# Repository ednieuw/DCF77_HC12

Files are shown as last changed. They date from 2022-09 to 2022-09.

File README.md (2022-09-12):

# DCF77_HC12
A HC-12 time transmitter with DCF77 time receiver
<h1 class="auto-style3">Arduino Nano Every as DCF77 time-transmitter <br />
with HC-12 433 MHz</h1>
<p class="auto-style1">
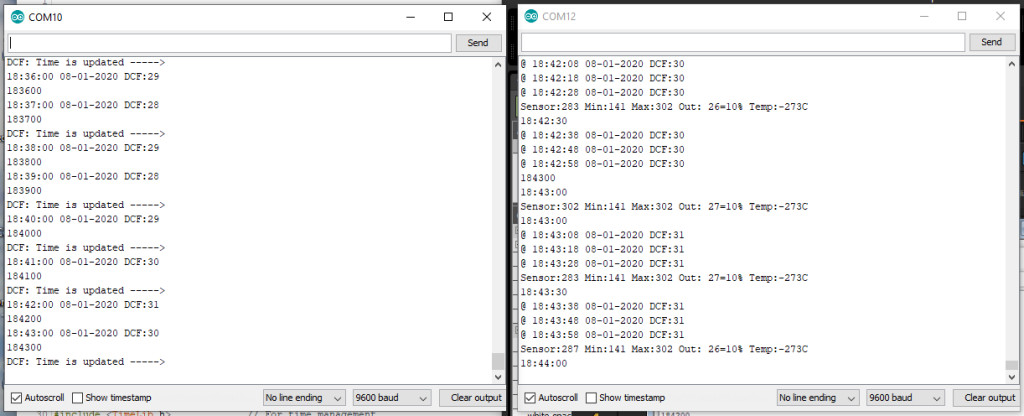
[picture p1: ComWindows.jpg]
Communication windows
<br />
</p>
<p class="auto-style1">The <a href="https://store.arduino.cc/arduino-nano-every">Arduino 
Nano Every</a> board is used to decode a 
DCF77-time signal received with a DCF77-ferrite receiver and transmits time and date 
<br />
with a HC-12 module 
in the air as text.<br />
The DCF77-signal is a pulse that is send every second into the ether with a length of 0.1 or 0.2 second. <br />
The short and long pulse represents a 0 and 1.<br />
When 59 bits are sent the program can extract the time date from this binary 
string. The 60th bit is a second pause without a pulse.<br />
<br />
<strong>Using interrupts</strong><br />
The standard Arduino DCF77-library of Thijs Ellenbaas was used to setup the 
program.<br />
Libraries are a good start but a disadvantage is that from one to the other day they are not available 
anymore. <br />
Because they must be robust and have many functions they often consume more program memory than necessary.<br />
Interrupts are nice but it are interrupts and therefore unpredictable.<br />
</p>
<p class="auto-style1"><strong>A different approach</strong><br />
Arduino programs runs in a loop. In this loop() input is checked and output generated by the subroutines called from within the loop().<br />
In our example the DCF77-signal can be read over 15000 time a second in this loop. <br />
Because the pulses are 0.1 or 0.2 second in length they can be easily discriminated from each other by just counting the 0 and 1 on the digital pin 
attached to the receiver. <br />
<br />
The start time of the counting is irrelevant as long as it is 1000 msec long. It is not necessary to wait for the rising or falling edge of the signal.<br />
Of course there must be enough counts (&gt;1000) in a second. Therefor the program may not use delays is one of its functions.<br />
<br />
The short pulse of 0.1 second must lie between 5% and 15% of the counts and the 1 pulse must lie between 15 and 30%.<br />
As a refinement one can start counting after say 100 successive counts otherwise it is a spike. This value will depend of how many counts a second the program 
can read<br />
This is the variable <em>DCFValidGate</em> in the program. <br />
<br />
In the picture below the DCF-signal with the 60 second-gap is shown.<br />
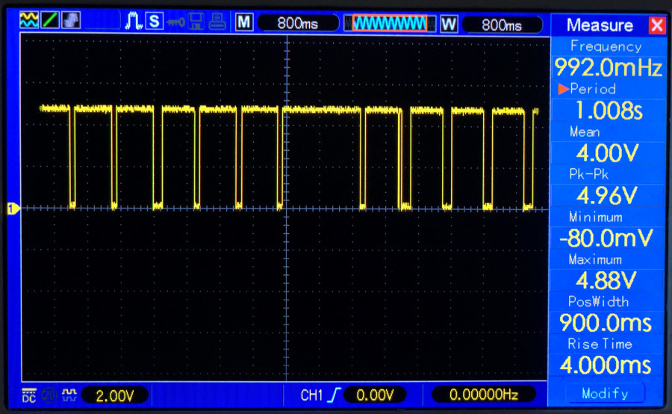
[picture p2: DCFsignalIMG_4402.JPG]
DCF-signal
<br />
<br />
The DCF77-signal is disturbed by microwaves, cheap power supplies and other electronics but also by 
WS2812 and SK6812 colour LED's. <br />
These LED's contain a small chip which frequency disturbs the signal if the 
receiver is close by.<br />
Also receivers that receive DCF49-, DCF39-&nbsp; and HGA22-signals are interfered by these chips.<br />
These RGB-colour chips are used in my <a href="https://ednieuw.nl">word clocks</a>.<br />
In contrast with the other modules like the <a href="https://www.mysensors.org/about/components">NRF24L01</a> 
and several 433 and 866 MHZ Transmitter/Receivers the <a href="https://howtomechatronics.com/tutorials/arduino/arduino-and-hc-12-long-range-wireless-communication-module/">HC-12 module</a> was very easy to implement and worked 
directly without complicated coding. It behaves as an ordinary RS232-connection.<br />
It can also easily be exchanged with HM-05 and HM10 Bluetooth modules without changing the connections and program code.<br />
The <a href="https://github.com/thijse/Arduino-DCF77">DCF-77 library of Thijs Ellenbaas</a> uses an interrupt routine to detect the signal. A tricky thing 
about interrupts is that the trigger is processor dependent and does not work on all pins in the ATMEGA chips. <br />
The usage of the <a href="https://store.arduino.cc/arduino-nano-every">Arduino 
Nano Every</a>&nbsp; was an experiment to see of the time transmitter would work 
with it. <br />
As expected the interrupts were different. For an Arduino Uno and Nano the interrupt number for pin 2 is 0&nbsp;and for the Nano Every 
interrupt number is 2.<br />
<br />
<strong>The hardware</strong><br />
The connections are simple. I used one of the PCB's that are used for the <a href="https://github.com/ednieuw/Fibonacci-Vierkantekokerklok">Fibonacci</a> and 
<a href="https://github.com/ednieuw/Word-Colour-Clock-SK6812-WS2812">Word</a> clocks.<br>
<a href="Colour%20Word%20Clock%20PCBV08-HC-12-DCF77.fzz">The Fritzing file is here</a><br />
The HC-12 module has similar connections as the HC-05 and HM-10 Bluetooth modules.<br />
Only RX and TX are reversed but this is taken care of in the coding.
<pre>
HC_12TX      = 6,    // HC-12 TX Pin
HC_12RX      = 7,    // HC-12 RX Pin </pre>
<p class="auto-style1">
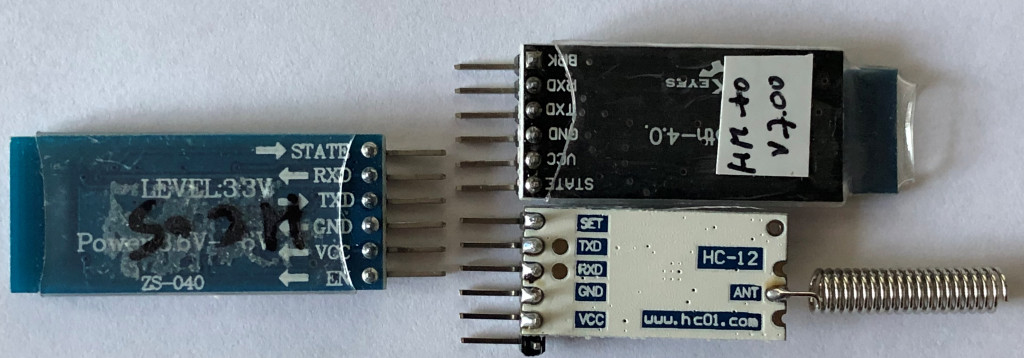
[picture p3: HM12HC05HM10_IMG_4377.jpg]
Connection on modules
<br /><br />
The 1.1K/2.2K voltage divider can be left out. Because several Bluetooth modules are not 5V tolerant a voltage divider is on this PCB to reduce the voltage to 3.3V.
<br />
The HC-12 can be connected directly to the Arduino pins but works also fine with the voltage divider. RX to TX and TX to RX!<br />
On <a href="https://www.allaboutcircuits.com/projects/understanding-and-implementing-the-hc-12-wireless-transceiver-module/">
this page the HC-12</a> and its programming is clearly explained (<a href="Implementing%20the%20HC-12%20Wireless%20transceiver.html">or 
use this link if the site has become obsolete</a>)</p>
<p class="auto-style1"><br />
<table style="width: 950px">
	<tr>
		<td valign="bottom">
		<a href="Colour%20Word%20Clock%20PCBV08-HC-12-DCF77.fzz">
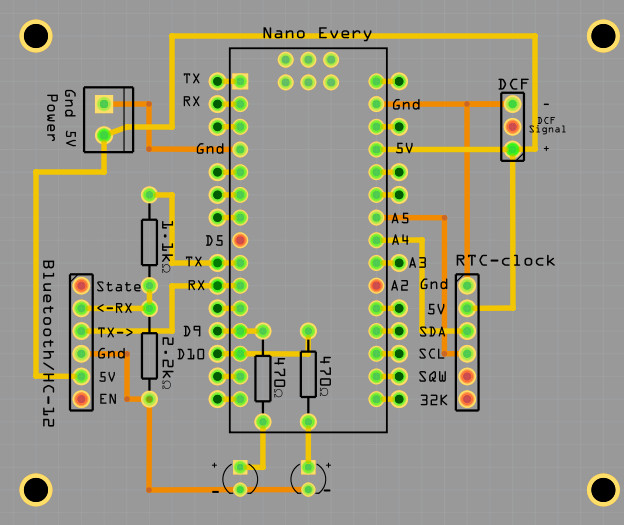
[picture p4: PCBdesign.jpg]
PCB
		</a></td>
		<td valign="bottom">
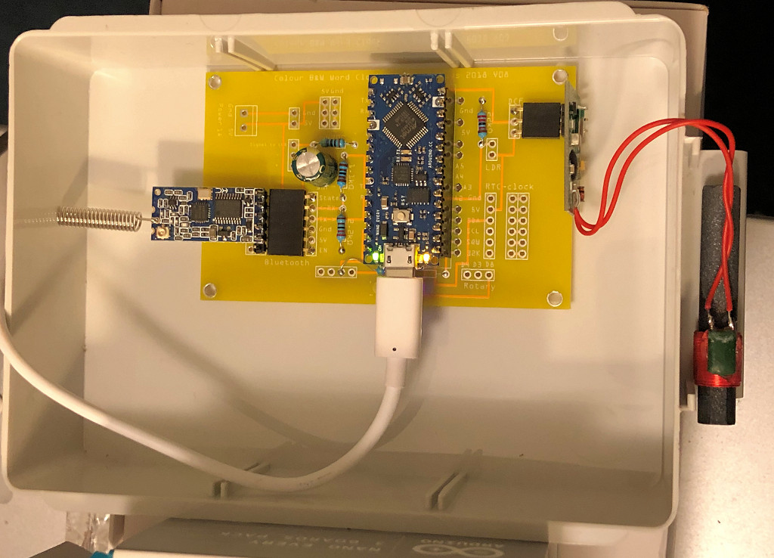
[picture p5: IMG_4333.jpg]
DCFHC12Every
		</td>
	</tr>
	<tr>
		<td valign="bottom">
		<a href="Colour%20Word%20Clock%20PCBV08-HC-12-DCF77.fzz" class="auto-style1">Fritzing PCB</a></td>
		<td valign="bottom">The transceiver running</td>
	</tr>
</table>
<br />
<strong>The program</strong><br />
Can be download here:&nbsp; 
<a href="DCF_HC12TransmitterV06.ino">
DCF_HC12TransmitterV06</a><br />
The libraries needed: <a href="Libraries.zip">Libraries.zip</a><br />
Copy the libraries Adafruit_BusIO, DCF77, NewliquidCrystal, RTClib and Time in the folder named 'libraries' located in your sketch folder<br />
The libraries EEPROM, HID, SoftwareSerial, SPI and Wire are standard default Arduino libraries. Use them only if the compiler can not find them.</p>
<p class="auto-style1">With the #define modules cq coding can be used or disabled. <br />
If no DS3231 module is installed the program uses the Arduino clock. This is fine when the DCF-receiver is working fine<br />
In this case no LCD is installed.</p>
<pre>#define DCFMOD           // Use the Arduino DCF77 library with interrupts
#define DCFTINY          // Use the Tiny DCF algorithm in this program
#define HC12MOD          // Use HC12 time transreceiver Long Range Wireless Communication Module
//#define LCDMOD           // LCD 2 x 16 installed 
#define MOD_DS3231       // DS3231 RTC module installed</pre>
<p class="auto-style1">After declarations, initialisations and the setup 
subroutine the program enters the loop.</p>
<p class="auto-style1"><strong>The loop</strong> is very simple&nbsp;
</p>
<pre>void loop(void)
{
 SerialCheck();
 EverySecondCheck();
 EveryMinuteUpdate();
                              #ifdef DCFMOD         
 DCF77Check();
                              #endif DCFMOD
}</pre>
<span class="auto-style1">The Serial- and DCF77-input is checked every loop and in this program that is over 15000 times a second.
In the EverySecondCheck routine the difference between the last time the routine was entered must be greater than 0.999 seconds.
After 50 msec the seconds tick LED is turned of. With the #ifdef part of the program are compiled or not compiled. <br>
It is wise to leave out program code for parts that are not used. It can only interfere and makes the program larger.
<pre>
</span><strong><span class="auto-style1">Every second</span>
</strong>void EverySecondCheck(void)
{
 if ( millis() - msTick &gt; 50)   { digitalWrite(secondsPin,LOW);}   // Turn OFF the second on pin 13
 if ( millis() - msTick &gt; 999)                                     // Flash the onboard Pin 13 Led so we know something is happening
  {    
   msTick = millis();                                              // second++; 
   digitalWrite(secondsPin,HIGH);                                  // turn ON the second on pin 13
   ++SecPulse;                                                     // second routine in function DimLeds
   GetTijd(0);                                                     // synchronize time with RTC clock      
                           #ifdef LCDMOD
   Print_tijd_LCD();
                           #endif LCDMOD  
                           #ifdef HC12MOD  // disabled with the x HC12MODx
   if( (Inow.second()==10) )               // When HC12 sends it disturbs DCF-signal. In seconds 1 - 19 are whether info bits
    {                                      // Now we can send some info
     sprintf(sptext,"@ %0.2d:%0.2d:%0.2d %0.2d-%0.2d-%0.4d DCF:%0.2d",
            Inow.hour(),Inow.minute(),Inow.second(),Inow.day(),Inow.month(),Inow.year(),DCF_signal);
     HC12.print(sptext);     
    }    
                            #endif HC12MOD
  }
}</pre>
 <class="auto-style1"><strong>Decoding the DCF77-signal</strong>
In the DCF77Check() routine the signal of the DCF77 is updated.
The Arduino library working with interrupts gives a DCFtime==TRUE if a valid time is calculated
In the case of the DCFtiny routine the digital signals are counted and every minute <a href="https://en.wikipedia.org/wiki/DCF77">decoded in UpdateDCFclock()</a>.

A scarcely used "if then else" is used in this routine:
<pre>    if (LastGateValid &gt; DCFValidGate ? SumSecondignal++ : DiscardedSignals++ );
    if (True ? then : else);</pre>
<pre>//--------------------------------------------
void DCF77Check(void)
{
 byte LHbit = 1 - digitalRead(DCF_PIN);        // write inverted DCF pulse to LED on board 
 digitalWrite(DCF_LED_Pin, LHbit ); 
                             #ifdef DCFMOD
 time_t DCFtime = DCF.getTime();               // Check if new DCF77 time is available
 if (DCFtime!=0)
  {
   Tekstprintln("DCF: Time is updated -----&gt;  ");
   sprintf(sptext,"%0.2d%0.2d%0.2d",Inow.hour(),Inow.minute(),Inow.second());
   Tekstprintln(sptext); 
   DCF_signal+=2;
   setTime(DCFtime); 
   RTCklok.adjust(DCFtime);
//   Ellenbaas++;
  }
                             #endif DCFMOD                             
                             #ifdef DCFTINY
 SumSignalCounts += 1;                         // Noof of counted signals  
 if(LHbit) 
   {
    LastGateValid++; 
    if (LastGateValid &gt; DCFValidGate ? SumSecondSignal++ : DiscardedSignals++ );
   }
 if ( millis() - DCFmsTick &gt; 999)              // Compute every second the received DCF-bit to a time 
    { 
      DCFmsTick = millis(); 
      if(byte OKstatus = UpdateDCFclock())     // if after 60 sec a valid time is calculated, sent it to the HC-12 module
         {
          if(OKstatus == 2)                    // if time flag was OK and date flag was NOK
            {
             sprintf(sptext," TIME OK --&gt; %0.2d:%0.2d",Dhour, Dminute );
             Serial.println(sptext);
             RTCklok.adjust(DateTime(Inow.year(), Inow.month(), Inow.day(), Dhour, Dminute, 0));
            }
           else                                // if time flag was OK and date flag also OK  (OKstatus == 1)
            {
            sprintf(sptext," TIME OK --&gt; %0.2d:%0.2d %0.2d-%0.2d-%0.4d/%0.1d",Dhour, Dminute, Dday, Dmonth, 2000+Dyear, Dwday );
            Serial.println(sptext);
            RTCklok.adjust(DateTime(2000+Dyear, Dmonth, Dday, Dhour, Dminute, 0));
            }         
          DCF_signal+=2;
 //         Ed++;
         }
    } 
                             #endif DCFTINY                  
 DCF_signal = constrain(DCF_signal,0 ,100);    // DCF_signal &lt;100
 analogWrite(DCFgood, DCF_signal); 
} 
                             #ifdef DCFTINY
//--------------------------------------------
// CLOCK Make the time from the received DCF-bits
//--------------------------------------------
byte UpdateDCFclock(void)
{
 byte TimeOK;              // return flag is proper time is computed
 if (Bitpos &gt;= 60) {Bitpos=0; StartOfMinute = 0;} 
 if (PrintDebugInfo)
    { 
    sprintf(sptext,"@ %5ld %5ld %3ld %2ld%% Bitpos: %2d",
    SumSecondSignal, SumSignalCounts, DiscardedSignals,  100 * SumSecondSignal/ SumSignalCounts, Bitpos );
    Serial.print(sptext);
    }  
 if (SumSignalCounts&gt;5000 &amp;&amp; SumSecondSignal&lt;500) Bitpos = 59;    // if enough signals the one second no signal is found. this is position zero
 Receivebit = 9;
 int msec = (int)1000 * SumSecondSignal/ SumSignalCounts;   
 switch(msec)
  {
   case   0 ...  50:  Receivebit = 9; break;  // if signal is less than 0.05 sec long than it is nothing
   case  51 ... 150:  Receivebit = 0; break;  // if signal is 0.1 sec long than it is a 0 
   case 151 ... 250:  Receivebit = 1; break;  // if signal is 0.1 sec long than it is a 1 
   default:           Receivebit = 2; break;  // in all other cases it is an error
  }
 if (PrintDebugInfo){ sprintf(sptext," Bit: %1d ",Receivebit );   Serial.print(sptext);}
 switch (Bitpos)                              // Ddecode the 59 bits to a time and date.
  {                                           // It is not binary but "Binary-coded decimal" 
                                              // and blocks are checked with an even parity bit. 
   case   0: if(Receivebit==0)       StartOfMinute = 1;                    break; // Bit must always be 0
   case   1 ... 19: Paritybit = 0;                                         break;
   case  20: if(Receivebit==1)
               {
                StartOfEncodedTime = 1;                      // Bit must always be 1
                Dsecond = Dminute = Dhour = Dday =Dwday = Dmonth = Dyear = 0;
                }
              else StartOfEncodedTime = 0;
                                                                           break;
   case  21: if(Receivebit==1) {Dminute  = 1;  Paritybit = 1 - Paritybit;} break;
   case  22: if(Receivebit==1) {Dminute += 2 ; Paritybit = 1 - Paritybit;} break;
   case  23: if(Receivebit==1) {Dminute += 4 ; Paritybit = 1 - Paritybit;} break;
   case  24: if(Receivebit==1) {Dminute += 8 ; Paritybit = 1 - Paritybit;} break;
   case  25: if(Receivebit==1) {Dminute += 10; Paritybit = 1 - Paritybit;} break;
   case  26: if(Receivebit==1) {Dminute += 20; Paritybit = 1 - Paritybit;} break;
   case  27: if(Receivebit==1) {Dminute += 40; Paritybit = 1 - Paritybit;} break;
   case  28: if(Receivebit==Paritybit) 
               {
                 if (PrintDebugInfo)
                  {                
                   sprintf(sptext,"(Min Parity OK %d %d)" ,Receivebit, Paritybit);
                   Serial.print(sptext);
                  }
                MinOK = 1;
               }
                else 
               {
                 if (PrintDebugInfo)
                  {                
                   sprintf(sptext,"(Min Parity NOK %d %d)",Receivebit, Paritybit);
                   Serial.print(sptext);
                  }
                MinOK = 0;
               }           
             Paritybit = 0;                                               break;  
   case  29: if(Receivebit==1) {Dhour   =  1; Paritybit = 1 - Paritybit;} break;
   case  30: if(Receivebit==1) {Dhour  +=  2; Paritybit = 1 - Paritybit;} break;
   case  31: if(Receivebit==1) {Dhour  +=  4; Paritybit = 1 - Paritybit;} break;
   case  32: if(Receivebit==1) {Dhour  +=  8; Paritybit = 1 - Paritybit;} break;
   case  33: if(Receivebit==1) {Dhour  += 10; Paritybit = 1 - Paritybit;} break;
   case  34: if(Receivebit==1) {Dhour  += 20; Paritybit = 1 - Paritybit;} break;
   case  35: if(Receivebit==Paritybit) 
                {
                 if (PrintDebugInfo)
                   {
                    sprintf(sptext,"(Hour Parity OK %d %d)", Receivebit, Paritybit);
                    Serial.print(sptext);
                   }                        
                  HourOK = 1;
                }
               else 
                {
                  if (PrintDebugInfo)
                   {
                    sprintf(sptext,"(Hour Parity NOK %d %d)",Receivebit, Paritybit); 
                    Serial.print(sptext);
                   }                  
                  HourOK = 0;
                }               
             Paritybit = 0;                                              break;  
   case  36: if(Receivebit==1) {Dday    =  1; Paritybit = 1 - Paritybit;} break;
   case  37: if(Receivebit==1) {Dday   +=  2; Paritybit = 1 - Paritybit;} break;
   case  38: if(Receivebit==1) {Dday   +=  4; Paritybit = 1 - Paritybit;} break;
   case  39: if(Receivebit==1) {Dday   +=  8; Paritybit = 1 - Paritybit;} break;
   case  40: if(Receivebit==1) {Dday   += 10; Paritybit = 1 - Paritybit;} break;
   case  41: if(Receivebit==1) {Dday   += 20; Paritybit = 1 - Paritybit;} break;
   case  42: if(Receivebit==1) {Dwday   =  1; Paritybit = 1 - Paritybit;} break;
   case  43: if(Receivebit==1) {Dwday  +=  2; Paritybit = 1 - Paritybit;} break;
   case  44: if(Receivebit==1) {Dwday  +=  4; Paritybit = 1 - Paritybit;} break;
   case  45: if(Receivebit==1) {Dmonth  =  1; Paritybit = 1 - Paritybit;} break;
   case  46: if(Receivebit==1) {Dmonth +=  2; Paritybit = 1 - Paritybit;} break;
   case  47: if(Receivebit==1) {Dmonth +=  4; Paritybit = 1 - Paritybit;} break;
   case  48: if(Receivebit==1) {Dmonth +=  8; Paritybit = 1 - Paritybit;} break;
   case  49: if(Receivebit==1) {Dmonth += 10; Paritybit = 1 - Paritybit;} break;
   case  50: if(Receivebit==1) {Dyear   =  1; Paritybit = 1 - Paritybit;} break;
   case  51: if(Receivebit==1) {Dyear  +=  2; Paritybit = 1 - Paritybit;} break;
   case  52: if(Receivebit==1) {Dyear  +=  4; Paritybit = 1 - Paritybit;} break;
   case  53: if(Receivebit==1) {Dyear  +=  8; Paritybit = 1 - Paritybit;} break;
   case  54: if(Receivebit==1) {Dyear  += 10; Paritybit = 1 - Paritybit;} break;
   case  55: if(Receivebit==1) {Dyear  += 20; Paritybit = 1 - Paritybit;} break;
   case  56: if(Receivebit==1) {Dyear  += 40; Paritybit = 1 - Paritybit;} break;
   case  57: if(Receivebit==1) {Dyear  += 80; Paritybit = 1 - Paritybit;} break;
   case  58: if(Receivebit==Paritybit) 
               {
                 if (PrintDebugInfo)
                   { 
                    sprintf(sptext,"(Year Parity OK %d %d0", Receivebit, Paritybit );
                    Serial.print(sptext);
                   }
                 YearOK = 1;
               }
             else
               {
                if (PrintDebugInfo)
                  {
                   sprintf(sptext,"(Year Parity NOK %d %d)",Receivebit, Paritybit ); 
                   Serial.print(sptext);
                  }
                 YearOK = 0;
               }
              Paritybit = 0;                                              break;  
    case  59: //Serial.print("silence");
    default:                                                              break;
   }
 Bitpos++;
 if (PrintDebugInfo)
    {
     sprintf(sptext," %0.2d:%0.2d %0.2d-%0.2d-%0.4d/%0.1d %d",Dhour, Dminute, Dday, Dmonth, 2000+Dyear, Dwday, Paritybit);
     Serial.println(sptext);
    }
 SumSecondSignal = SumSignalCounts = DiscardedSignals = LastGateValid = DiscardedSignals = 0;
 if(Bitpos == 59)
   {
   if(StartOfEncodedTime &amp;&amp; MinOK &amp;&amp; HourOK &amp;&amp; YearOK)
     {                                          // check is the time differ only one minute from the previous time
      uint32_t TimeNow = (((((Dyear * 12 + Dmonth) * 31) + Dday) * 24) + Dhour) * 60 + Dminute;
//      sprintf(sptext," Time now  %ld  :: Previous  %ld",TimeNow , TimePrevious); Serial.println(sptext);
      if(TimeNow - TimePrevious &lt;= 2)           // Time is valid if difference with previous time is one minute
        {
         TimeOK = 1;    
        }
      TimePrevious = TimeNow;      
      } 
    else                                        // Time is not valid
      {
       if(StartOfEncodedTime &amp;&amp; MinOK &amp;&amp; HourOK)
         {                                      // check is the time differ only one minute from the previous time
          uint32_t TimeNow = Dhour * 60 + Dminute; 
                                                // sprintf(sptext," HourMinTime now  %ld  :: Previous  %ld",TimeNow , HourMinPrevious); Serial.println(sptext);
          if(abs(TimeNow - HourMinPrevious &lt;= 2))    // Time is valid if difference with previous time is one minute
            {
             TimeOK = 2;    
            }
          HourMinPrevious = TimeNow;         
          }
        else                                    // if no vslid time stamp add one minute to time previous
          {
           TimePrevious++;
           TimeOK = 0;       
          }
       } 
   }                                            // --- end if(Bitpos == 59)
return(TimeOK);
}                 
                             #endif DCFTINY</pre>
<p class="auto-style1"><strong>Rounding up</strong><br />
</p>
<p class="auto-style1">The rest of the program explains it self. <br />
The definition below takes care of the interrupt pin definition of the Nano 
Every and other Arduino's.<br />
</p>
<pre>                    #ifdef ARDUINO_AVR_NANO_EVERY
#define DCF_INTERRUPT 2               // DCF Interrupt number associated with DCF_PIN ( 2 Nano Every)
                    #else if
#define DCF_INTERRUPT 0              // Nano Uno etc 
                    #endif      
DCF77 DCF = DCF77(DCF_PIN,DCF_INTERRUPT,LOW);
                    #endif DCFMOD </pre>
<pre><span class="auto-style1">It is possible to use both DCF decoding routines simultaneously or one of the two. </span>
//#define DCFMOD           // Use the Arduino DCF77 library with interrupts
#define DCFTINY          // Use the Tiny DCF algorithm in this program</pre>
Entering a letter A in the serial monitor switches on and off de debugger for the DCFtiny decoding 
algorithm.<br />
If all the parities are OK and time differs one or two minutes from the previous 
time, date and time are send<br />
If only time parities are OK time is send and not the date.<br />
<br />
The DCFtiny generates earlier and more valid time results than the interrupt 
library.<br />
DCFtiny is probably a little less robust then the interrupt library.<br />
But checking if the received time string from the HC12-transmitter is valid is 
almost obligatory until an CRC-check is 
built in the transmission sentence. <br />
<br />
<br />
<span class="auto-style14"><strong>@ pos cnt tot cnt, DCFValidGate, length%, 
bitpos, bit value, compiled time, compiled date/weekday, parity bit</strong></span><br />
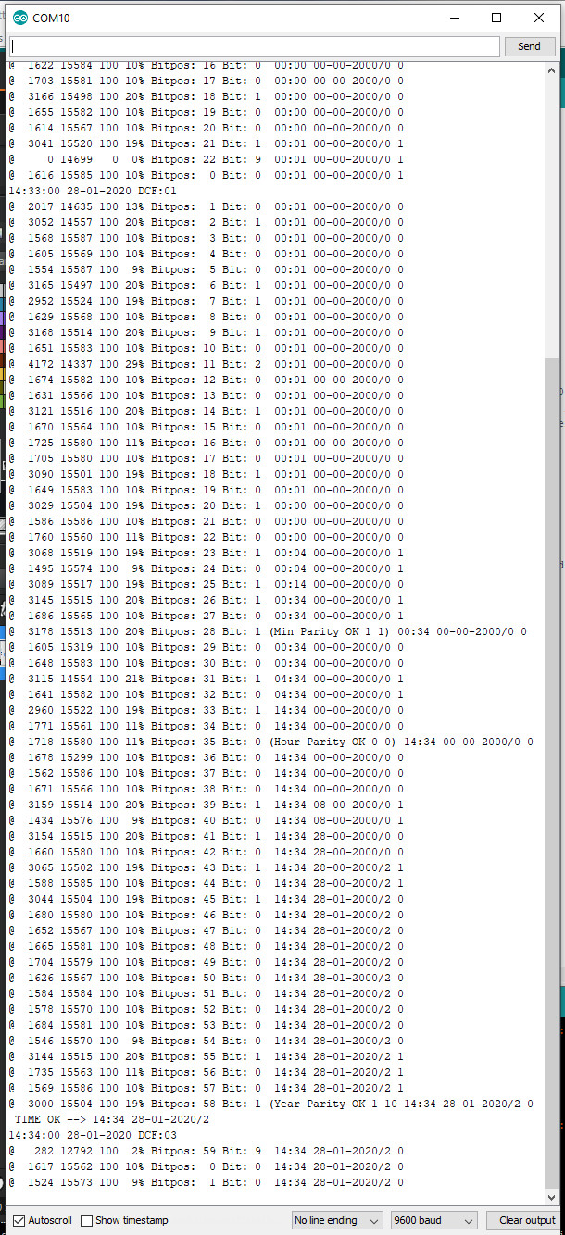
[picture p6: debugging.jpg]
Debugging the signal
<br />
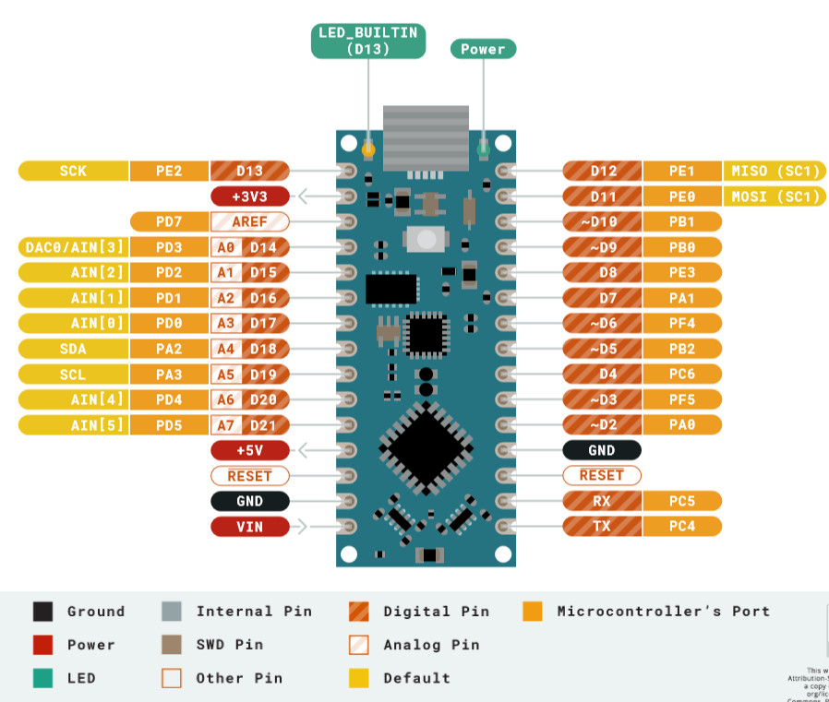
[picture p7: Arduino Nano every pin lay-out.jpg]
Arduino Nano Every pin layout
<br />
<p class="auto-style1">Links</p>
<p class="auto-style1">
<a href="http://www.brettoliver.org.uk/DCF77_Analyzer_Clock/DCF77_Analyzer_Clock.htm">
<span class="auto-style19">Arduino DCF77 Signal Analyzer Clock </span></a>
<span class="auto-style16"><br class="auto-style18" />
</span>
<span class="auto-style16" style="display: inline !important; float: none; background-color: rgb(255, 255, 255); color: rgb(0, 0, 0); font-style: normal; font-variant: normal; font-weight: 400; letter-spacing: normal; orphans: 2; text-align: left; text-decoration: none; text-indent: 0px; text-transform: none; -webkit-text-stroke-width: 0px; white-space: normal; word-spacing: 0px;">
<a href="http://www.hansonline.eu/service/rc.htm"><span class="auto-style18">
Radio Controlled (RC) of Funk klokken</span></a></span><span class="auto-style16"><br class="auto-style18" />
<a href="https://arduino-projekte.webnode.at/meine-projekte/">
<span class="auto-style18">Meine Arduino-Projekte </span></a>
<br class="auto-style18" />
</span>
<a href="http://www.dcf77logs.de/WebConsole.aspx" style="color: rgb(0, 102, 204); font-family: Verdana,Geneva,Tahoma,sans-serif; font-size: 16px; font-style: normal; font-variant: normal; font-weight: 400; letter-spacing: normal; orphans: 2; text-align: left; text-decoration: underline; text-indent: 0px; text-transform: none; -webkit-text-stroke-width: 0px; white-space: normal; word-spacing: 0px;">
<span class="auto-style17">Online signal from Mainflingen on website</span></a><br class="auto-style17" style="color: rgb(0, 0, 0); font-style: normal; font-variant: normal; font-weight: 400; letter-spacing: normal; orphans: 2; text-align: left; text-decoration: none; text-indent: 0px; text-transform: none; -webkit-text-stroke-width: 0px; white-space: normal; word-spacing: 0px;" />
<span class="auto-style17" style="color: rgb(0, 0, 0); font-style: normal; font-variant: normal; font-weight: 400; letter-spacing: normal; orphans: 2; text-align: left; text-decoration: none; text-indent: 0px; text-transform: none; -webkit-text-stroke-width: 0px; white-space: normal; word-spacing: 0px;">
Explains the bits in the received string </span>
<a href="http://arduino-projects4u.com/home-weather-station/" style="color: rgb(0, 102, 204); font-family: Verdana,Geneva,Tahoma,sans-serif; font-size: 16px; font-style: normal; font-variant: normal; font-weight: 400; letter-spacing: normal; orphans: 2; text-align: left; text-decoration: underline; text-indent: 0px; text-transform: none; -webkit-text-stroke-width: 0px; white-space: normal; word-spacing: 0px;">
<span class="auto-style17">Arduino projects 4you</span></a><br class="auto-style17" style="color: rgb(0, 0, 0); font-style: normal; font-variant: normal; font-weight: 400; letter-spacing: normal; orphans: 2; text-align: left; text-decoration: none; text-indent: 0px; text-transform: none; -webkit-text-stroke-width: 0px; white-space: normal; word-spacing: 0px;" />
<span class="auto-style17" style="color: rgb(0, 0, 0); font-family: Verdana,Geneva,Tahoma,sans-serif; font-style: normal; font-variant: normal; font-weight: 400; letter-spacing: normal; orphans: 2; text-align: left; text-decoration: none; text-indent: 0px; text-transform: none; -webkit-text-stroke-width: 0px; white-space: normal; word-spacing: 0px;">
HKW-Elektronik GmbH&nbsp; </span>
<a href="http://www.hkw-shop.de/Empfangstechnik-AM/" style="color: rgb(0, 102, 204); font-family: Verdana,Geneva,Tahoma,sans-serif; font-size: 16px; font-style: normal; font-variant: normal; font-weight: 400; letter-spacing: normal; orphans: 2; text-align: left; text-decoration: underline; text-indent: 0px; text-transform: none; -webkit-text-stroke-width: 0px; white-space: normal; word-spacing: 0px;">
<span class="auto-style17">Sells all kinds of receivers</span></a><br class="auto-style17" style="color: rgb(0, 0, 0); font-style: normal; font-variant: normal; font-weight: 400; letter-spacing: normal; orphans: 2; text-align: left; text-decoration: none; text-indent: 0px; text-transform: none; -webkit-text-stroke-width: 0px; white-space: normal; word-spacing: 0px;" />
<a href="http://www.hjberndt.de/soft/rtctftdcf.html" style="color: rgb(0, 102, 204); font-family: Verdana,Geneva,Tahoma,sans-serif; font-size: 16px; font-style: normal; font-variant: normal; font-weight: 400; letter-spacing: normal; orphans: 2; text-align: left; text-decoration: underline; text-indent: 0px; text-transform: none; -webkit-text-stroke-width: 0px; white-space: normal; word-spacing: 0px;">
<span class="auto-style15"><span class="auto-style18">Rheinturmfunkuhr mit 
Arduino </span></span></a>
<br class="auto-style17" style="color: rgb(0, 0, 0); font-style: normal; font-variant: normal; font-weight: 400; letter-spacing: normal; orphans: 2; text-align: left; text-decoration: none; text-indent: 0px; text-transform: none; -webkit-text-stroke-width: 0px; white-space: normal; word-spacing: 0px;" />
<a href="https://gonium.net/md/2006/11/05/arduino-dcf77-radio-clock-receiver/index.html" style="color: rgb(0, 102, 204); font-family: Verdana,Geneva,Tahoma,sans-serif; font-size: 16px; font-style: normal; font-variant: normal; font-weight: 400; letter-spacing: normal; orphans: 2; text-align: left; text-decoration: underline; text-indent: 0px; text-transform: none; -webkit-text-stroke-width: 0px; white-space: normal; word-spacing: 0px;">
<span class="auto-style17">Arduino DCF77 radio clock receiver ,Matthias 
Dalheimer </span></a>
<br class="auto-style17" style="color: rgb(0, 0, 0); font-style: normal; font-variant: normal; font-weight: 400; letter-spacing: normal; orphans: 2; text-align: left; text-decoration: none; text-indent: 0px; text-transform: none; -webkit-text-stroke-width: 0px; white-space: normal; word-spacing: 0px;" />
<a href="https://github.com/thijse/" style="color: rgb(0, 102, 204); font-family: Verdana,Geneva,Tahoma,sans-serif; font-size: 16px; font-style: normal; font-variant: normal; font-weight: 400; letter-spacing: normal; orphans: 2; text-align: left; text-decoration: underline; text-indent: 0px; text-transform: none; -webkit-text-stroke-width: 0px; white-space: normal; word-spacing: 0px;">
<span class="auto-style15"><span class="auto-style18">Github Thijs Elenbaas</span></span></a><br class="auto-style17" style="color: rgb(0, 0, 0); font-style: normal; font-variant: normal; font-weight: 400; letter-spacing: normal; orphans: 2; text-align: left; text-decoration: none; text-indent: 0px; text-transform: none; -webkit-text-stroke-width: 0px; white-space: normal; word-spacing: 0px;" />
<span class="auto-style17">
<a href="http://www.conrad.com/ce/en/product/641138/DCF-receiver-board" style="color: rgb(0, 102, 204); font-family: Verdana,Geneva,Tahoma,sans-serif; font-size: 16px; font-style: normal; font-variant: normal; font-weight: 400; letter-spacing: normal; orphans: 2; text-align: left; text-decoration: underline; text-indent: 0px; text-transform: none; -webkit-text-stroke-width: 0px; white-space: normal; word-spacing: 0px;">
Conrad receiver</a></span><br />
<a href="https://www.makerguides.com/tm1637-arduino-tutorial/">TM1637 4 Digit 7 
Segment Display Arduino Tutorial </a><br />
<a href="https://www.allaboutcircuits.com/projects/understanding-and-implementing-the-hc-12-wireless-transceiver-module/">
Understanding and Implementing the HC-12 Wireless Transceiver Module</a> </p>
<p class="auto-style1">
&nbsp;</p>
<p class="auto-style1">February 2020</p>
<a href="../../email.html">Ed Nieuwenhuys</a><br /></p>

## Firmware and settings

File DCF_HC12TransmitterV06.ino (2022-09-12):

// =============================================================================================================================
/* 
This Arduino code works on a ATMEGA328 ( Nano Uno), ATMEGA1284 chip and Nano Every
This source contains code for the following modules:  
- RTC DS3231 clock module
- LDR light sensor 5528
- HC-12 Long Range Wireless Communication Module
- DCF77 module DCF-2
The DCF77 module reads the time and date from the German longwave DCF-77 time signal
The time and date are transmitted as ASCII string as hhmmss. (031500 = 15 minutes past 3)
The date is hourly transmitted with a prefic D followed by ddmmyyyy ( D01042020 - 1 april 2020)
Comments are transmitted with a prefix @ (@ 10:07:38 09-01-2020 DCF:16)

Ed Nieuwenhuys 2020
 V06 sep 2022 Removed warnings
 */
// ===============================================================================================================================

//--------------------------------------------
// ARDUINO Definition of installed modules
//--------------------------------------------
#define DCFMOD           // Use the Arduino DCF77 library with interrupts
#define DCFTINY          // Use the Tiny DCF algorithm in this program
#define HC12MOD          // Use HC12 time transreceiver Long Range Wireless Communication Module
#define LCDMOD           // LCD 2 x 16 installed 
#define MOD_DS3231       // DS3231 RTC module installed
//--------------------------------------------
// ARDUINO Includes defines and initialysations
//--------------------------------------------

#include <Wire.h>
#include "RTClib.h"
#include "Time.h"
#include <TimeLib.h>             // For time management 
#include <EEPROM.h>
                     #ifdef LCDMOD
#include <LCD.h>
#include <LiquidCrystal_I2C.h>
                     # endif // LCDMOD
                     #ifdef DCFMOD
#include "DCF77.h"
                     # endif // DCFMOD
                     #ifdef HC12MOD
#include <SoftwareSerial.h>              // For HC12
                     # endif // HC12MOD  
//--------------------------------------------
// PIN Assigments
//--------------------------------------------                      
enum DigitalPinAssignments {      // Digital hardware constants ATMEGA 328 ----
 RX           = 0,                // Connects to TX
 TX           = 1,                // Connects to RX
 DCF_PIN      = 2,                // DCFPulse on interrupt pin
 PIN03        = 3,                // PIN 3
 PIN04        = 4,                // PIN 4
 PIN05        = 5,                // PIN 5
// BT_RX        = 6,                // Tx-pin on BT-mod
// BT_TX        = 7,                // Rx-pin on BT-mod 
 HC_12TX      = 6,                // HC-12 TX Pin
 HC_12RX      = 7,                // HC-12 RX Pin  
 PIN08        = 8,                // PIN 8 
 secondsPin   = 8,                // Seconds
 LED09        = 9,                // PIN 9 
 DCFgood      = 10,               // DCF-signal > 50
 PIN11        = 11,               // PIN 11
 PIN12        = 12,               // PIN 12 
 DCF_LED_Pin  = 13,               // Show DCF-signal
 };
 
enum AnaloguePinAssignments {     // Analogue hardware constants ----
 PhotoCellPin = 2,                // A2
 EmptyA3      = 3,                // A3
 SDA_pin      = 4,                // SDA pin
 SCL_pin      = 5};               // SCL pin

//--------------------------------------------
// HC-12 Long Range Wireless Communication Module
//--------------------------------------------
                     #ifdef HC12MOD
SoftwareSerial HC12(HC_12TX, HC_12RX); //rxPin, txPin, inverse_logic.
                                       //rxPin: the pin on which to receive serial data 
                                       //txPin: the pin on which to transmit serial data
                     # endif // HC12MOD 
//--------------------------------------------
// CLOCK
//--------------------------------------------                                 
#define MAXTEXT 50
static  uint32_t msTick;          // the number of millisecond ticks since we last incremented the second counter
int     count; 
int     Delaytime = 200;
byte    Isecond, Iminute, Ihour, Iday, Imonth, Iyear; 
byte    Dsecond, Dminute, Dhour, Dday, Dmonth, Dyear, Dwday; 
byte    lastminute = 0, lasthour = 0, sayhour = 0;
byte    SecPulse           = 0;   // give a pulse to the Isecond led

const byte MenuItems = 7;          // No of entries in menu
const char menu[MenuItems][MAXTEXT] PROGMEM = {
 "DCF HC12 Transmitter V06",
 "Enter time as:hhmm (1321) or hhmmss (132145)",
 "A DCF Debug info On/Off", 
 "D D15122017 for date 15 December 2017",
 "G for DCF-signalinfo on display",
 "I for this info",
 "Ed Nieuwenhuys" };

//--------------------------------------------
// DS3231 CLOCK MODULE
//--------------------------------------------
#define DS3231_I2C_ADDRESS          0x68
#define DS3231_TEMPERATURE_MSB      0x11
#define DS3231_TEMPERATURE_LSB      0x12

        #ifdef MOD_DS3231
RTC_DS3231 RTCklok;    //RTC_DS1307 RTC; 
        #else
RTC_Millis RTCklok;   
        # endif //
DateTime Inow;
                    #ifdef DCFMOD 
//--------------------------------------------
// DCF-2 DCF77 MODULE
//--------------------------------------------
                    #ifdef ARDUINO_AVR_NANO_EVERY
#define DCF_INTERRUPT 2               // DCF Interrupt number associated with DCF_PIN ( 2 Nano Every)
                    #else
#define DCF_INTERRUPT 0              // Nano Uno etc 
                    # endif //      
DCF77 DCF = DCF77(DCF_PIN,DCF_INTERRUPT,LOW); // HIGH (HKW) or LOW (Reichelt). Some DCF modules invert the signal
                    # endif // DCFMOD 

byte     DCF_signal         = 1;     // is a proper time received? (0 - 100)
                    #ifdef DCFTINY
static   uint32_t DCFmsTick;         // the number of millisecond ticks since we last incremented the second counter
uint32_t SumSecondSignal    = 0;     // sum of digital signal ( 0 or 1)
uint32_t SumSignalCounts    = 0;     // Noof of counted signals
uint32_t DiscardedSignals   = 0;     // Noof of discarded counted signals
uint32_t TimePrevious       = 0;     // Previous minute time and date
uint32_t HourMinPrevious    = 0;     // Previous minute time

byte     Bitpos             = 0;
byte     StartOfMinute      = 0;
byte     StartOfEncodedTime = 0;
byte     Receivebit         = 0;
byte     Paritybit          = 0;
int      LastGateValid      = 0;      // Counter to start recording a DCF-signal after DCFValidGate received
int      DCFValidGate       = 100;    // If LastGateValid reaches this value a DCF-signal is recorded
byte  MinOK, HourOK, YearOK = 0;
                    # endif // DCFTINY
                    #ifdef LCDMOD
//--------------------------------------------
// LCD Module
//--------------------------------------------
LiquidCrystal_I2C lcd(0x27,2,1,0,4,5,6,7); // 0x27 is the I2C bus address for an unmodified backpack
                    # endif // 
//----------------------------------------
// Common
//----------------------------------------
byte PrintDebugInfo         = 0;      // for showing debug info for DCFTINY
char sptext[MAXTEXT+2];               // for common print use    
int  MilliSecondValue       = 999;    // The duration of a second  minus 1 ms. Used in Demo mode
uint32_t Ed =0, Ellenbaas = 0;
// --------------------------------------------------------------------------
// End Definitions                                                    
// --------------------------------------------------------------------------
//--------------------------------------------
// ARDUINO Loop
//--------------------------------------------
void loop(void)
{
 SerialCheck(); 
 EverySecondCheck();
 EveryMinuteUpdate();
//                              #ifdef DCFMOD         
 DCF77Check();
//                              # endif // DCFMOD
}  
//--------------------------------------------
// ARDUINO Setup
//--------------------------------------------
void setup()
{                                        
 Serial.begin(9600);                                                // Setup the serial port to 9600 baud                                                        // Start the RTC-module  
 Wire.begin();                                                      // Start communication with I2C / TWI devices                            
 pinMode(DCF_LED_Pin, OUTPUT);                                      // For showing DCF-pulse or other purposes
 pinMode(DCF_PIN,     INPUT_PULLUP);
// pinMode(BT_State,    INPUT_PULLUP);
// pinMode(BT_Break,    OUTPUT );   
 pinMode(DCFgood,     OUTPUT );  
 pinMode(secondsPin,  OUTPUT );
                              #ifdef MOD_DS3231
 RTCklok.begin();                                                   // start the RTC-module
                              # else
 RTCklok.begin(DateTime(F(__DATE__), F(__TIME__)));                 // if no RTC module is installed use the ATMEGAchip clock
                              # endif // MOD_DS3231  
                              #ifdef DCFMOD
 DCF.Start();                                                      // Start the DCF-module
 Tekstprintln("DCF enabled");
                              # endif // DCFMOD
                     #ifdef DCFTINY
 DCFmsTick = millis();                                              // Start of DCF 1 second loop
                     # endif // DCFTINY
                              #ifdef LCDMOD
 lcd.begin (16,2); // for 16 x 2 LCD module                         // Activate LCD module
 lcd.setBacklightPin(3,POSITIVE);
 lcd.setBacklight(HIGH);
 Tekstprintln("LCD enabled");
                              # endif // LCDMOD
      #ifdef ARDUINO_AVR_NANO_EVERY
 Tekstprintln("ARDUINO_AVR_NANO_EVERY enabled");
       # endif //
      
                              #ifdef HC12MOD
 HC12.begin(9600);               // Serial port to HC12
 Tekstprintln("HC-12 time sender enabled");
                             # endif // HC12MOD 
 DateTime now = RTCklok.now();
 DateTime compiled = DateTime(__DATE__, __TIME__);
 if (now.unixtime() < compiled.unixtime()) 
  {
   Serial.println(F("RTC is older than compile time! Updating"));   // Following line sets the RTC to the date & time this sketch was compiled
   RTCklok.adjust(DateTime(F(__DATE__), F(__TIME__))); 
  }
// SumSecondSignal = SumSignalCounts = 0;
 msTick = millis();                                      // Used in KY-040 rotary for debouncing and seconds check
 SWversion();                                                       // Display the version number of the software
 GetTijd(0);                                                        // Get the time and store it in the proper variables
//  Setup_BluetoothCentralMode();
 } 
//--------------------------------------------
// CLOCK Version info
//--------------------------------------------
void SWversion(void) 
{ 
 for (int n=0; n<52; n++) {Serial.print(F("_"));} Serial.println();
 for (int i = 0; i < MenuItems; i++)   {strcpy_P(sptext, menu[i]);   Tekstprintln(sptext);  }
 for (int n=0; n<52; n++) {Serial.print(F("_"));} Serial.println();
}
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
